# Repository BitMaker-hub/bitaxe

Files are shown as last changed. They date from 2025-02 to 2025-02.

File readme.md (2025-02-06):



# The Nerdaxe
NerdAxe is a fork from bitaxe with fullcolor display graphics. NerdAxe is indented to be an upgrade board for these who have a NerdMiner and would like to have more powerful mining features without losing the NerdMiner essence. That's why NerdAxe is currently controlled by the common board used on Nerdminer project called TTGO-TDisplayS3.

Currently exists two variants sepparated in two branches:
- **Nerdaxe Gamma**: 1,2Th with a single chip BM1370. [Nerdaxe Gamma](https://github.com/BitMaker-hub/NerdAxe/tree/gamma-1%2C2Ths)
- **Nerdaxe Ultra**: 0,5Th with a single chip BM1366. [Nerdaxe Ultra](https://github.com/BitMaker-hub/NerdAxe/tree/ultra-500Ghs)

The following fork could not be possible without the previous work of @skot, @ben & bitaxe devs. [Check bitaxe project](https://bitaxe.org)

Upgrade your NerdMiner experience throught this addon board and start playing with ASICs

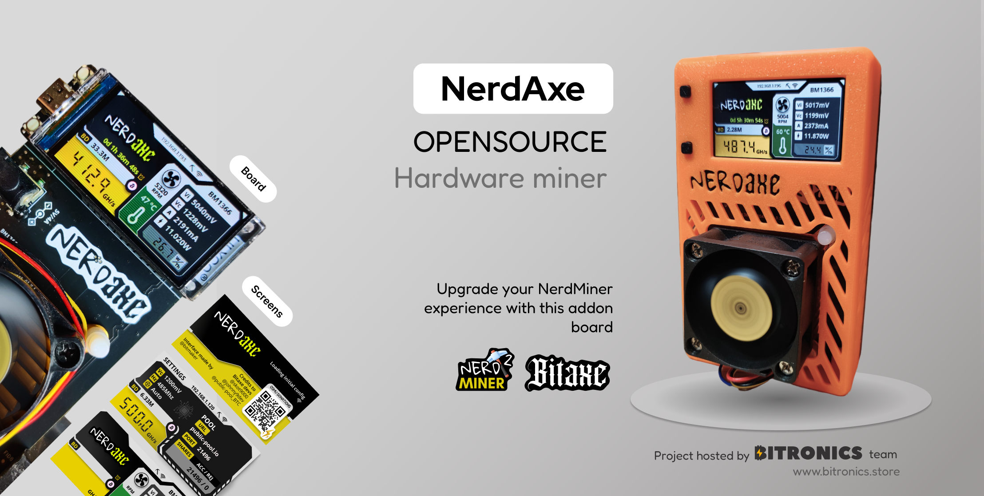
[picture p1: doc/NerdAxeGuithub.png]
NerdAxeUltra design


## Goals
- **Plug&Play**: your NerdMiner board and convert it into a NerdAxe.
- **Standalone**: can mine directly to your pool over WiFi. No External computer needed.
- **Embedded**: low cost, low maintenance, high availability, high reliability, low power.
- **ASIC**: working with most efficient ASIC chips from Bitmain - BM1370.
- **Versatile**: solo/pool mining, autotune power/heat/efficiency.
- **Open Source**: All design files are provided.

## Features
- **TTGO-TDisplay** ESP32s3 wifi microcontroller display board
- **Multiple Screens** to allow you see all the miner stats 
- **TI TPS546D** buck regulator steps down the 5V input to power the BM1370
- **Microchip EMC2101** PWM controls the fan and monitors tach output. Measuring internal die temp isn't working.

## Software & Firmware
Nerdaxe firmware was forked from original ESP-Miner version and adapted to use TTGO board and LVGL as graphic interface lib. 
Check it here -> [ESP-Miner Nerdaxe version](https://github.com/BitMaker-hub/ESP-Miner-NerdAxe)

**Today** Nerdaxe is using the latest evolution of this firmware modified by @pmaxuw (creator of the NerdQaxe) and used for other multiple boards
Current firmware -> [ESP-Miner Nerd\*axe version](https://github.com/shufps/ESP-Miner-NerdQAxePlus)

Flash the latest Nerdaxe firmware here: 
- Go to flasher online tool: https://flasher.bitronics.store/ (recommend via Google Chrome incognito mode)
- Nerd\*axe flasher online tool: https://shufps.github.io/nerdqaxe-web-flasher/  

## The DIY area

### Asic BM1370
- The BM1370 is a undocumented SHA256 mining ASIC from Bitmain. It's mostly used in the Antminer S21pro/S21+
- Bitmain claims the BM1370 has 0.021J/GH efficiency
- The BM1370 is available (new) for around $60 each in small quantities.
- The BM1370 has a different footprint and pinout from the MB1366, BM1368 in previous bitaxe.

### Other components & build troubleshooting
- BM1370 from NBTC on AliExpress
- [40x40mm heatsink and 5V fan](https://www.aliexpress.com/item/2251832861666365.html) from a random AliExpress seller. At least half of these arrived broken in some way. But they are cheap and the working ones do keep the BM1387's nice and cool when used with some thermal compound.
    - Swap this fan with the [Noctua NF-A4x10](https://noctua.at/en/products/fan/nf-a4x10-pwm) 5V 4-Pin fan for a much more pleasant experience.
- Board is designed with [KiCad 8](https://www.kicad.org) design files
- All of the parts on the board are listed in the KiCad BOM
- Check out [building.md](building.md) for PCB ordering tips
- Check out [assembly.md](assembly.md) for assembly tips

### Power Supply Requirements
- 5VDC Power supply 5A minimum. Should be capable of over 25W

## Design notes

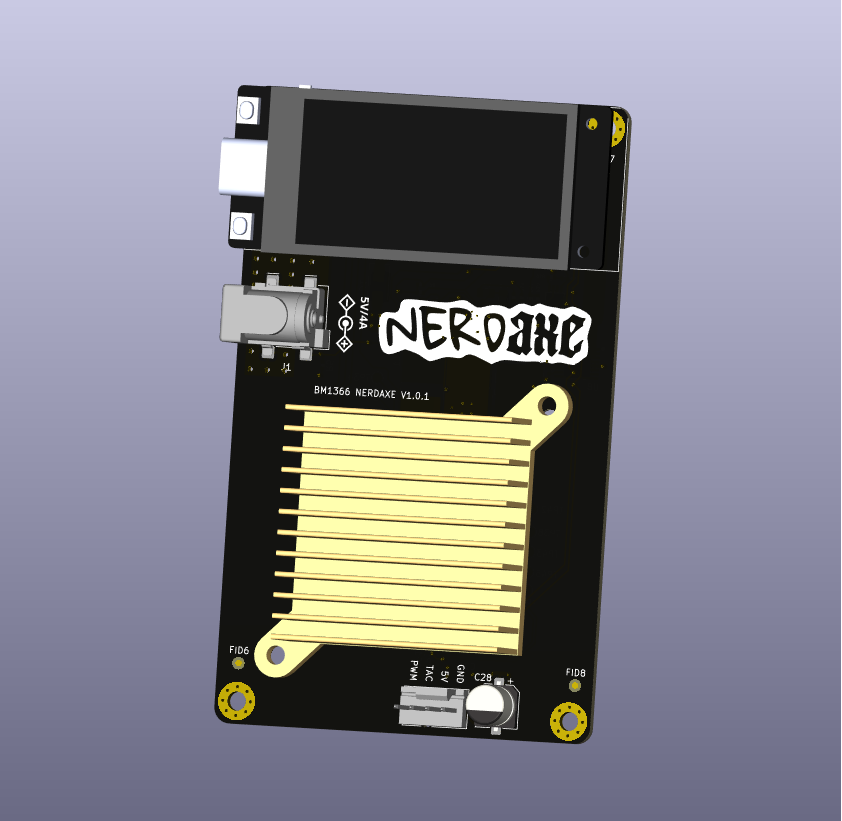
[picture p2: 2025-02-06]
doc/NerdAxe.png

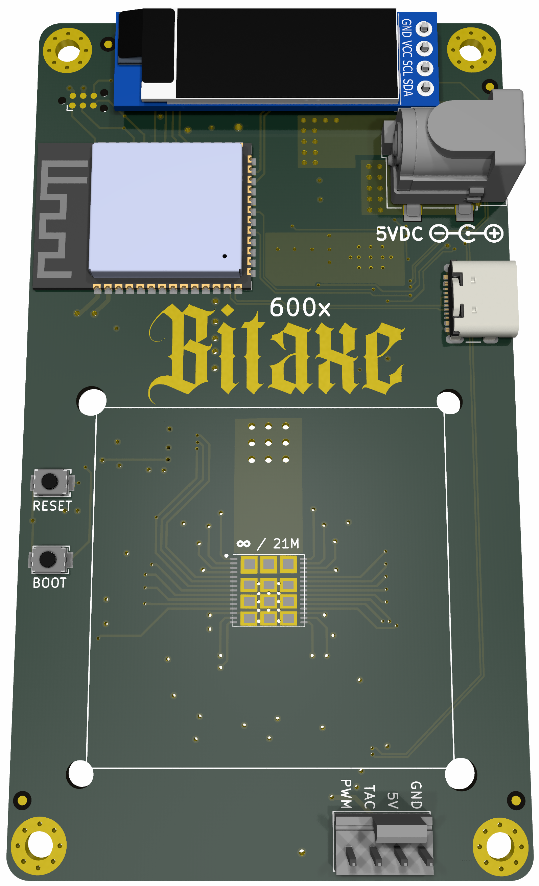
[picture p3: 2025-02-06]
doc/render.png

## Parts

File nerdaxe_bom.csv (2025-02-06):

Qty | Reference | Value | Footprint | DK | LCSC | Description
1 | C2 | 10uF | Capacitor_SMD:C_0805_2012Metric | 1276-1096-1-ND
1 | C6 | 4700pF | Capacitor_SMD:C_0402_1005Metric | 490-1309-1-ND
1 | C9 | 2200pF | Capacitor_SMD:C_0402_1005Metric | 490-8257-1-ND
1 | C10 | 4.7uF | Capacitor_SMD:C_0402_1005Metric | 490-14306-1-ND
1 | C11 | 1000pF | Capacitor_SMD:C_0805_2012Metric | 311-1127-1-ND
1 | C13 | 100pF | Capacitor_SMD:C_0402_1005Metric | 732-7431-1-ND
1 | C50 | 470pF | Capacitor_SMD:C_0402_1005Metric | 1276-1566-1-ND
21 | C1 C5 C7 C26 C27 C28 C30 C31 C32 C33 C34 C35 C36 C39 C40 C41 C42 C44 C45 C46 C48 | 1uF | Capacitor_SMD:C_0402_1005Metric | 587-5514-1-ND
3 | C14 C15 C16 | 22uF | Capacitor_SMD:C_0805_2012Metric | 490-10746-1-ND
5 | C17 C18 C19 C20 C43 | 100uF | Capacitor_SMD:C_1206_3216Metric | 1276-1782-1-ND |  | -- valores mixtos --
3 | C3 C4 C51 | 47uF | Capacitor_SMD:C_1210_3225Metric | 1276-3376-1-ND
9 | C8 C12 C29 C37 C38 C47 C49 C52 C53 | 0.1uF | Capacitor_SMD:C_0402_1005Metric | 1276-1234-1-ND
1 | D1 | SMAJ5.0A | Diode_SMD:D_SMA |  |  | 400W unidirectional Transient Voltage Suppressor | 5.0Vr | SMA(DO-214AC)
1 | J1 | 54-00164 | bitaxe:TENSILITY_54-00164 | 839-54-00164CT-ND | C431534 | DC Barrel Jack with an internal switch
1 | J6 | Conn_01x04 | bitaxe:470531000 | WM4330-ND
1 | L1 | 300nH | bitaxe:SLC1175-271MEC_COC
1 | R1 | 8.25k | Resistor_SMD:R_0402_1005Metric | 311-8.25KLRCT-ND
1 | R5 | 14.7k | Resistor_SMD:R_0402_1005Metric | YAG2984CT-ND
1 | R8 | 3.74k | Resistor_SMD:R_0402_1005Metric | 311-3.74KLRCT-ND
1 | R9 | 11.8k | Resistor_SMD:R_0402_1005Metric | YAG2958CT-ND
1 | R10 | 68.1k | Resistor_SMD:R_0402_1005Metric | YAG3213CT-ND
1 | R11 | 10 | Resistor_SMD:R_0402_1005Metric | 311-10.0LRCT-ND
1 | R12 | 1 | Resistor_SMD:R_1206_3216Metric | CSR1206FT1R00CT-ND
1 | R24 | 5.6k | Resistor_SMD:R_0402_1005Metric | 13-RC0402FR-135K6LCT-ND
2 | R13 R14 | 49.9 | Resistor_SMD:R_0402_1005Metric | 311-49.9LRCT-ND
3 | R15 R17 R25 | 10k | Resistor_SMD:R_0402_1005Metric | 311-10KJRCT-ND
2 | R18 R19 | 1k | Resistor_SMD:R_0402_1005Metric | 311-1.00KLRCT-ND
2 | R22 R23 | 100 | Resistor_SMD:R_0402_1005Metric | 311-100LRCT-ND
2 | R6 R21 | 0 | Resistor_SMD:R_0402_1005Metric | -- valores mixtos --
1 | U2 | TPS546D24ARVFR | bitaxe:LQFN40-CLIP | 296-TPS546D24ARVFRCT-ND
1 | U5 | MCP1824T-1202E/OT | Package_TO_SOT_SMD:SOT-23-5 | MCP1824T-1202E/OTCT-ND
1 | U6 | MCP1824T-0802E | Package_TO_SOT_SMD:SOT-23-5 | MCP1824T-0802E/OTCT-ND
1 | U7 | 25MHz | bitaxe:SMD3225-4P |  | C5137262
1 | U8 | BM1370_mode1 | bitaxe:BM1370
1 | U9 | SN74AVC4T774 | Package_SO:TSSOP-16_4.4x5mm_P0.65mm | 296-24739-1-ND
1 | U10 | EMC2101 | Package_SO:TSSOP-8_3x3mm_P0.65mm | EMC2101-R-ACZL-CT-ND
1 | U11 | T-Display-S3 | bitaxe:T-Display-S3

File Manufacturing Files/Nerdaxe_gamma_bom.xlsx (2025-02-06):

Comment | Designator | Footprint | JLCPCB part
4700pF (GRM155R71E472KA01D) | C6 | Condensador 0402 4700PF 25V X7R estándar | C1538
2200pF (GRM155R61H222KA01D) | C9 | Condensador 0402 2200PF 50V X5R | C1531
4.7uF | C10 | Condensador 0402 4.7UF 10V X5R estándar | C191541
1000pF | C11 | Condensador 0805 1000pF 50V estándar | C94121
100pF | C13 | Condensador 0402 100pF/50V XR7 estándar | C281750
470pF | C50 | Condensador 0402 470pF/50V XR7 estándar | C272887
1uF | C1, C5, C7, C26, C27, C28, C30, C31, C32, C33, C34, C35, C36, C39, C40, C41, C42, C44, C45, C46, C48 | Condensador 0402 1uF 16V XR5 estándar | C113791
22uF (GRM21BR61A226ME44L) | C14, C15, C16 | Condensador 0805 22uF 10V estándar | C29277
100uF (CL31A107MQHNNNE) | C17, C18, C19, C20, C43 | Condensador 1206 100uF 6.3V XR5 estándar | C87164
10uF | C2 | Condensador 0805 10uF 16V XR5 estándar | C89827
47uF (CL32A476KOJNNNE) | C3, C4, C51 | Condensador 1210 47uF 16V XR5 estándar | C412625
0.1uF | C8, C12, C29, C37, C38, C47, C49, C52, C53 | Condensador 0402 100nF 16V estándar | C1525
SMAJ5.0A | D1 | SMAJ5.0A | C113952
US1D | D2 | Diode_SMD:D_SMA | C5140042
Conn_01x04 | J6 | 470531000 | C240840
8.25k | R1 | Resistencia 0402 8.25k estandar | C95598
14.7k | R5 | Resistencia 0402 14k7 1% estandar | C881164
0 | R6, R21 | Resistencia 0402 0ohm estandar | C106231
3.74k | R8 | Resistencia 0402 3.74k 1% estandar | C15172
11.8k | R9 | Resistencia 0402 11.8k 1% estandar | C93752
68.1k | R10 | Resistencia 0402 68.1k 1% estandar | C11537
10 | R11 | Resistencia 0402 10ohm 1% estandar | C25139
1 | R12 | Resistencia 1206 1ohm 1% estandar | C17928
5.6k | R24 | Resistencia 0402 5k6 1% estandar | C365033
49.9 | R13, R14 | Resistencia 0402 49.9 1% estandar | C477760
10k | R15, R17, R25 | Resistencia 0402 10k 1% estandar | C269674
1k | R19 | Resistencia 0402 1k 1% estandar | C11702
100 | R22, R23 | Resistencia 0402 100 1% estandar | C25076
TPS546D24ARVFR | U2 | TPS546D24ARVFR | C507280
MCP1824T-1202E/OT | U5 | MCP1824T-1202E/OT | C58464
MCP1824T-0802E | U6 | MCP1824T-0802E/OT | C625460
SX3M25.000E20F30THN | U7 | 25MHz - SX3M25.000E20F30THN | C5137262
SN74AVC4T774PWR | U9 | SN74AVC4T774PWR - TSSOP-16 | C129363
EMC2101-R-ACZL-TR | U10 | EMC2101 - TSSOP-8 | C626968
 | Observaciones
 | Muy atentamente,

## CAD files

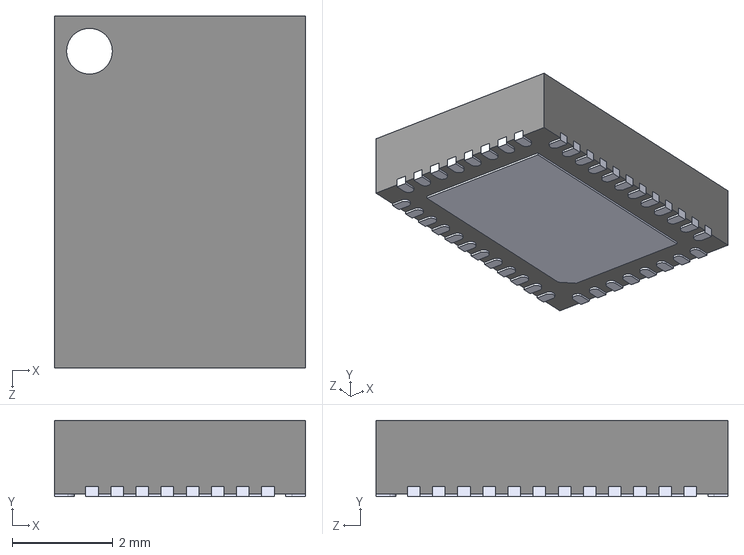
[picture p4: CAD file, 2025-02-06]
3d/TPS546D24ARVFR.step
5.00 x 1.52 x 7.00 mm

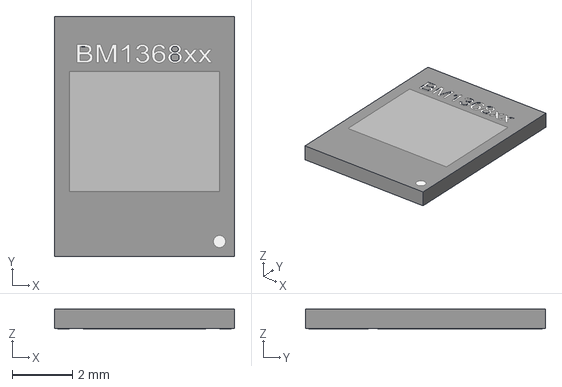
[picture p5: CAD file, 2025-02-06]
3d/BM1368xx.stp
6.00 x 8.00 x 0.65 mm

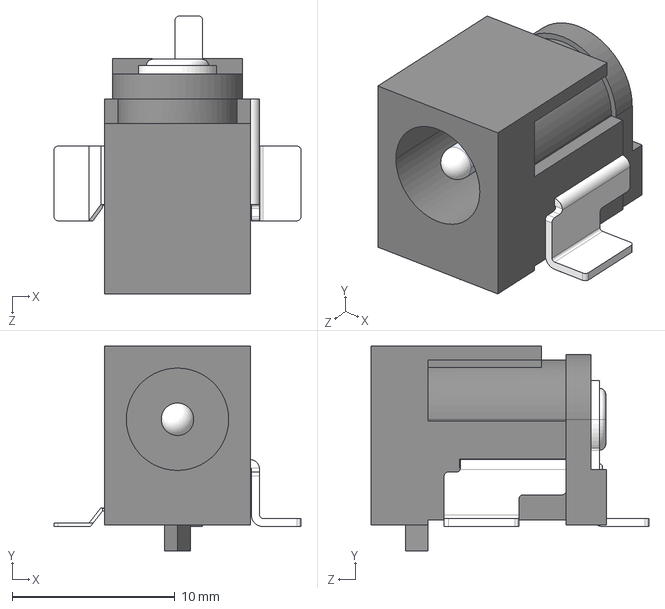
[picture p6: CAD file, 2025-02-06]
3d/CUI_DEVICES_PJ-036AH-SMT-TR.step
15.2 x 12.6 x 17.1 mm

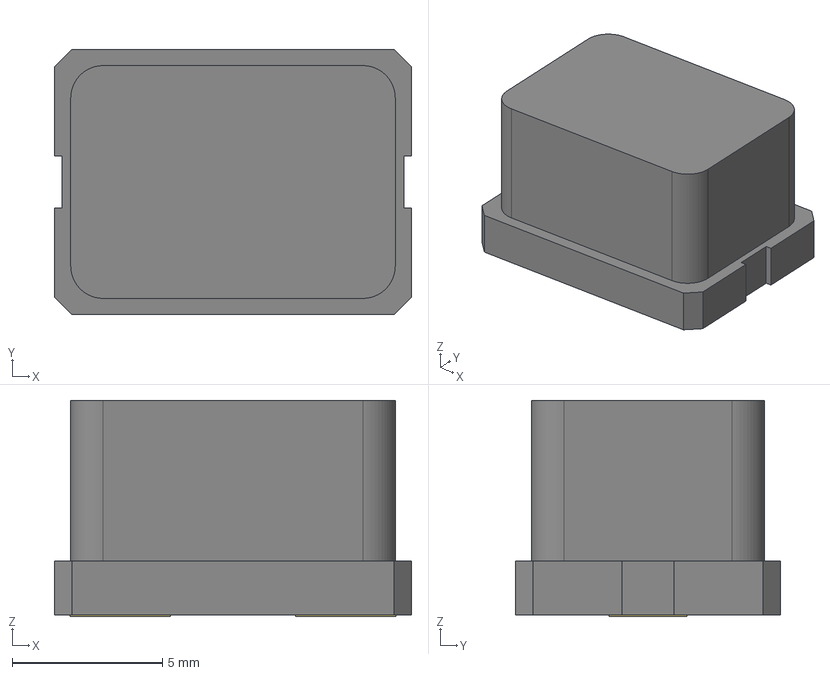
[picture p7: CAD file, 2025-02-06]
3d/SLC1175-271MEC_COC.step
11.9 x 8.83 x 7.19 mm

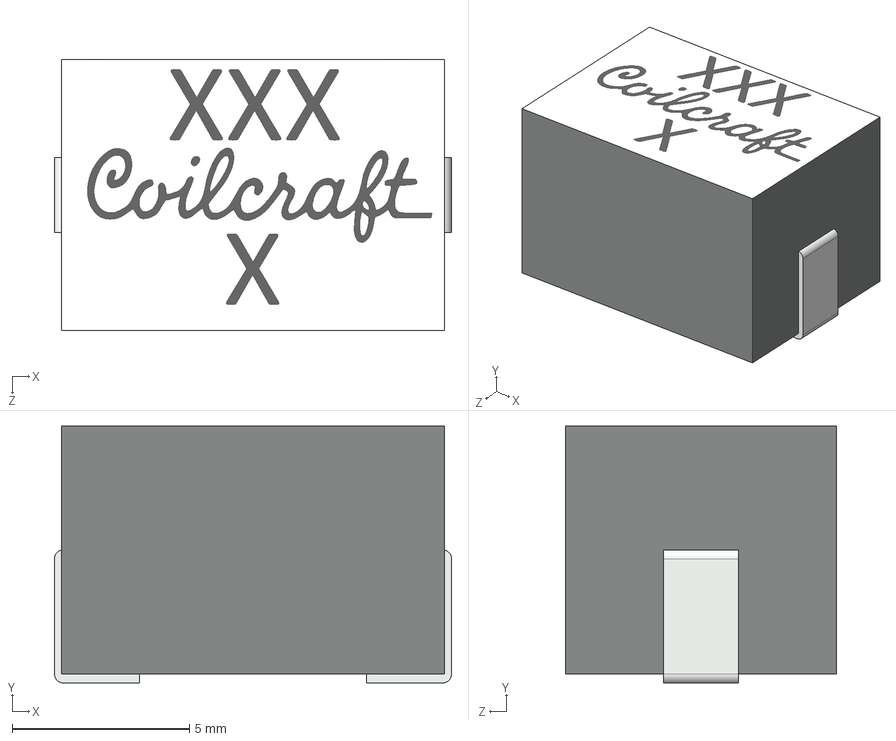
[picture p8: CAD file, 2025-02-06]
3d/Coilcraft-SLC1175.STEP
11.2 x 7.25 x 7.65 mm

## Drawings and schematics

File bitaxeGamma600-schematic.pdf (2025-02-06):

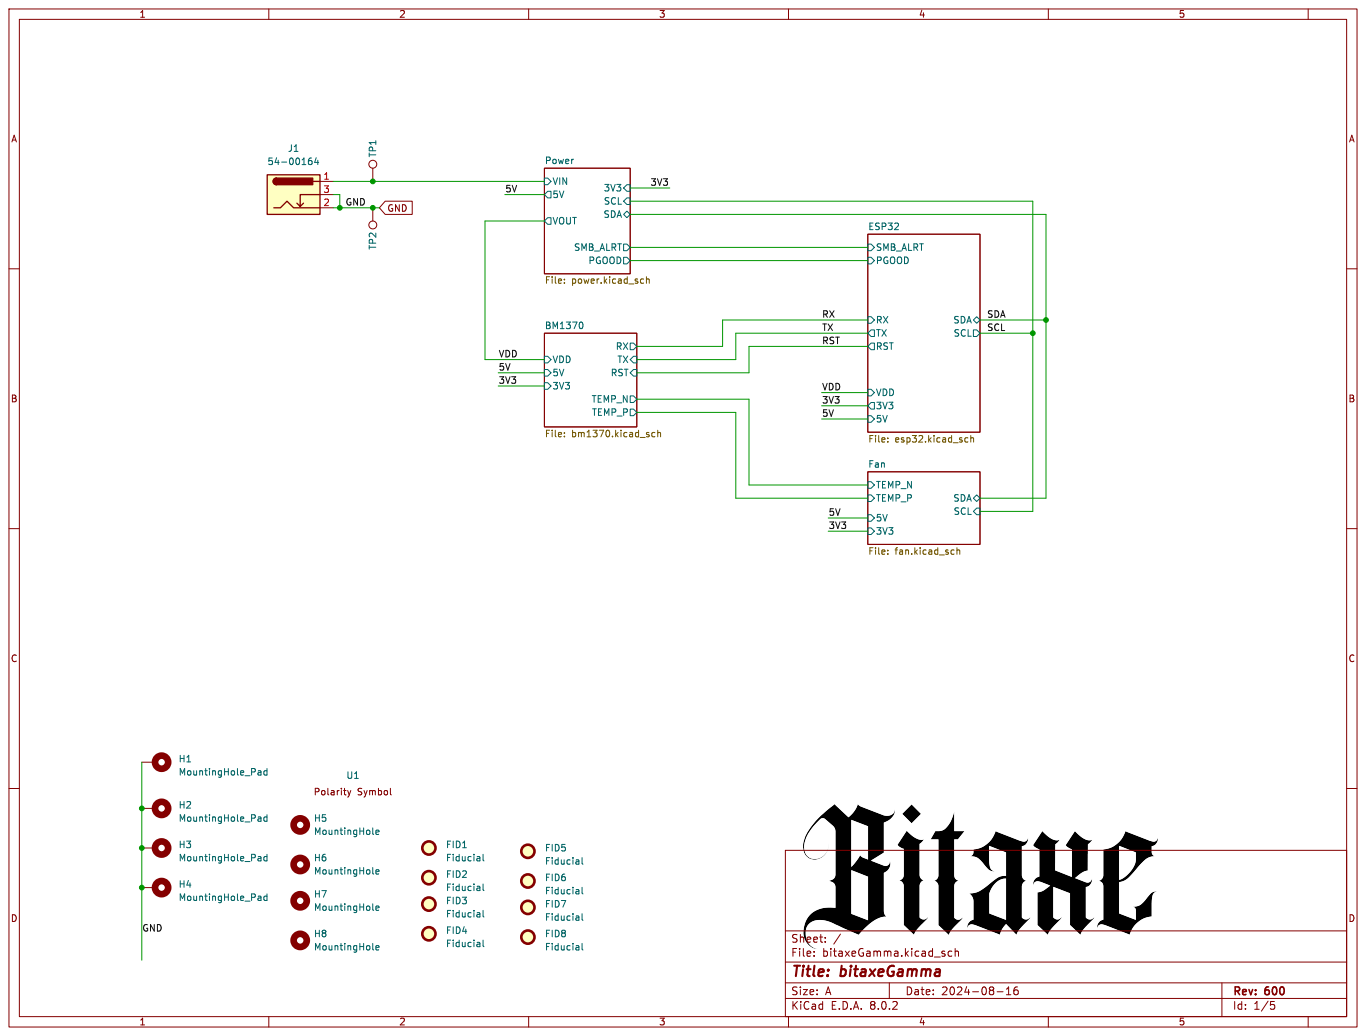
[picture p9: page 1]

Fan File: fan.kicad_sch TXRX RST

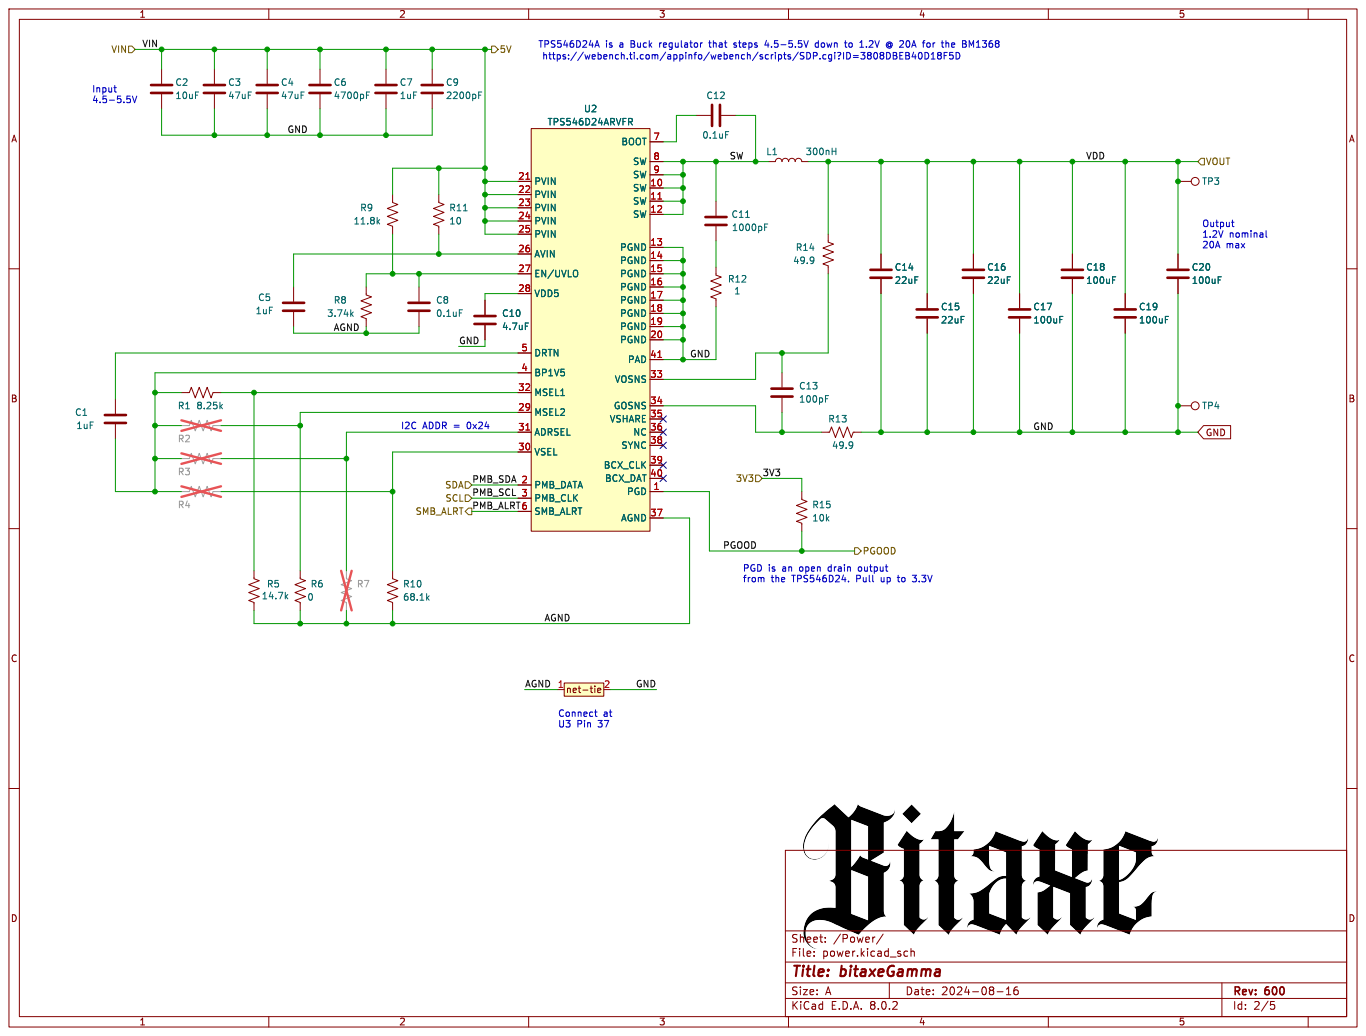
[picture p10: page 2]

https://webench.ti.com/appinfo/webench/scripts/SDP.cgi?ID=3808DBEB40D18F5D

File: power.kicad_sch Sheet: /Power/
Id: 2/5 Title: bitaxeGamma

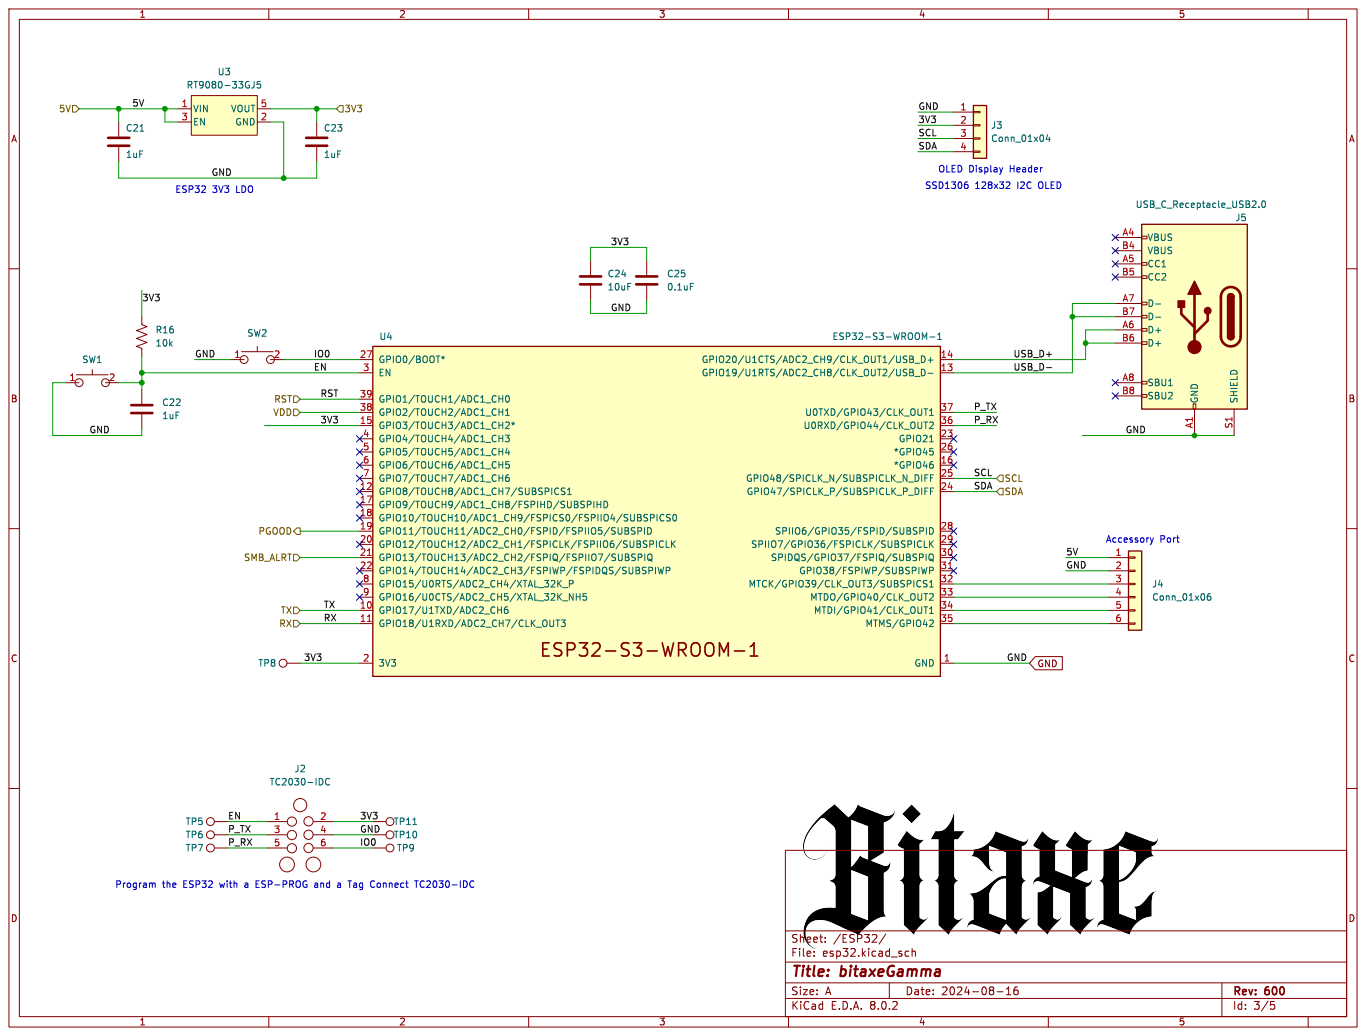
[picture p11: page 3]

Program the ESP32 with a ESP-PROG and a Tag Connect TC2030-IDC

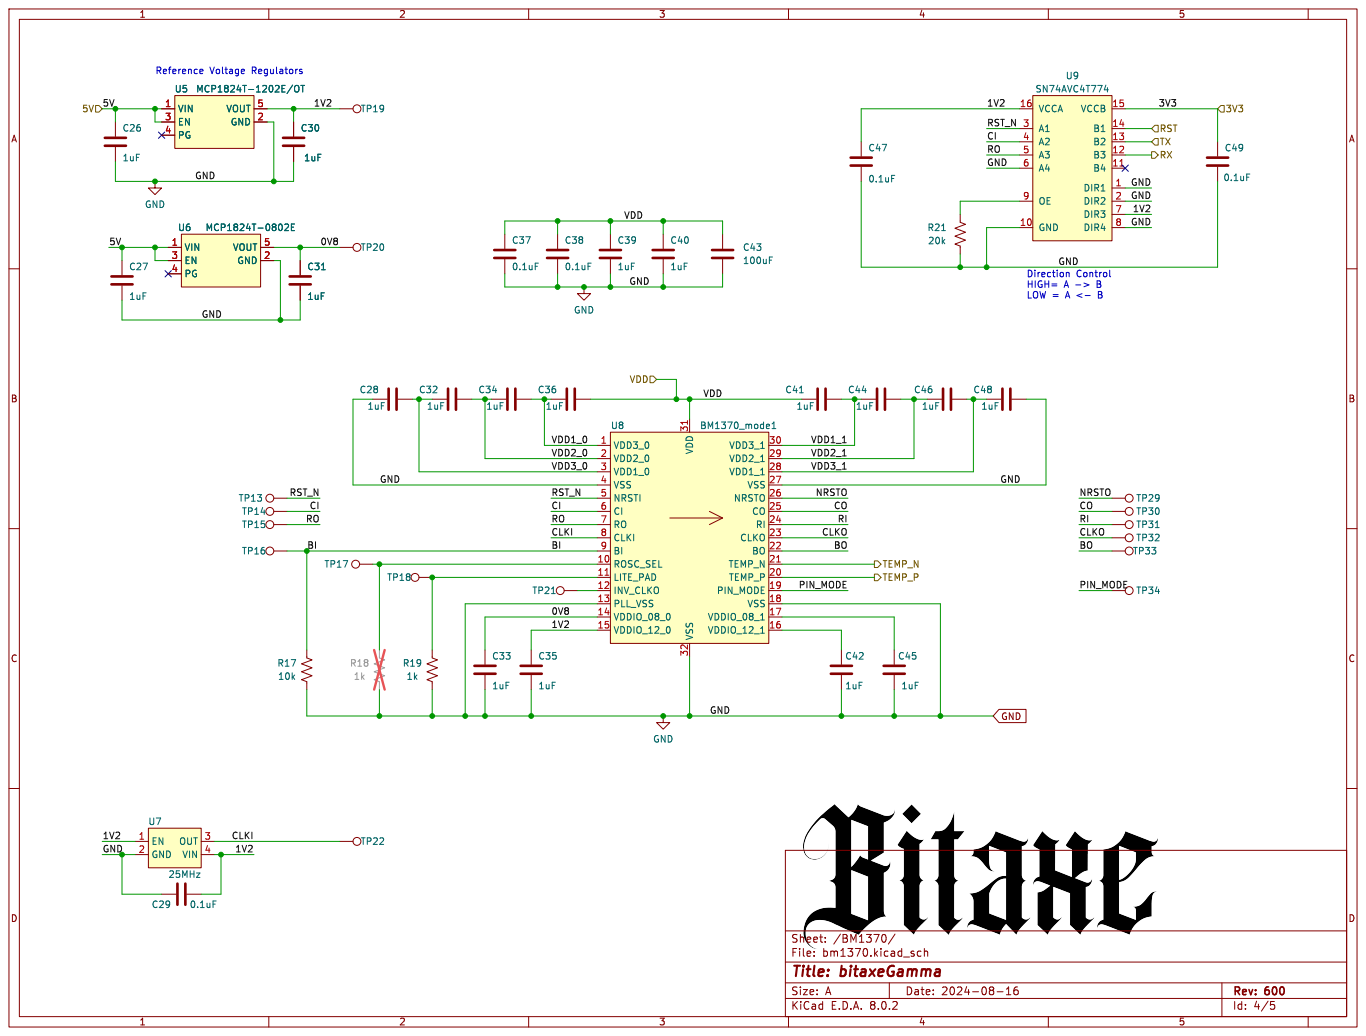
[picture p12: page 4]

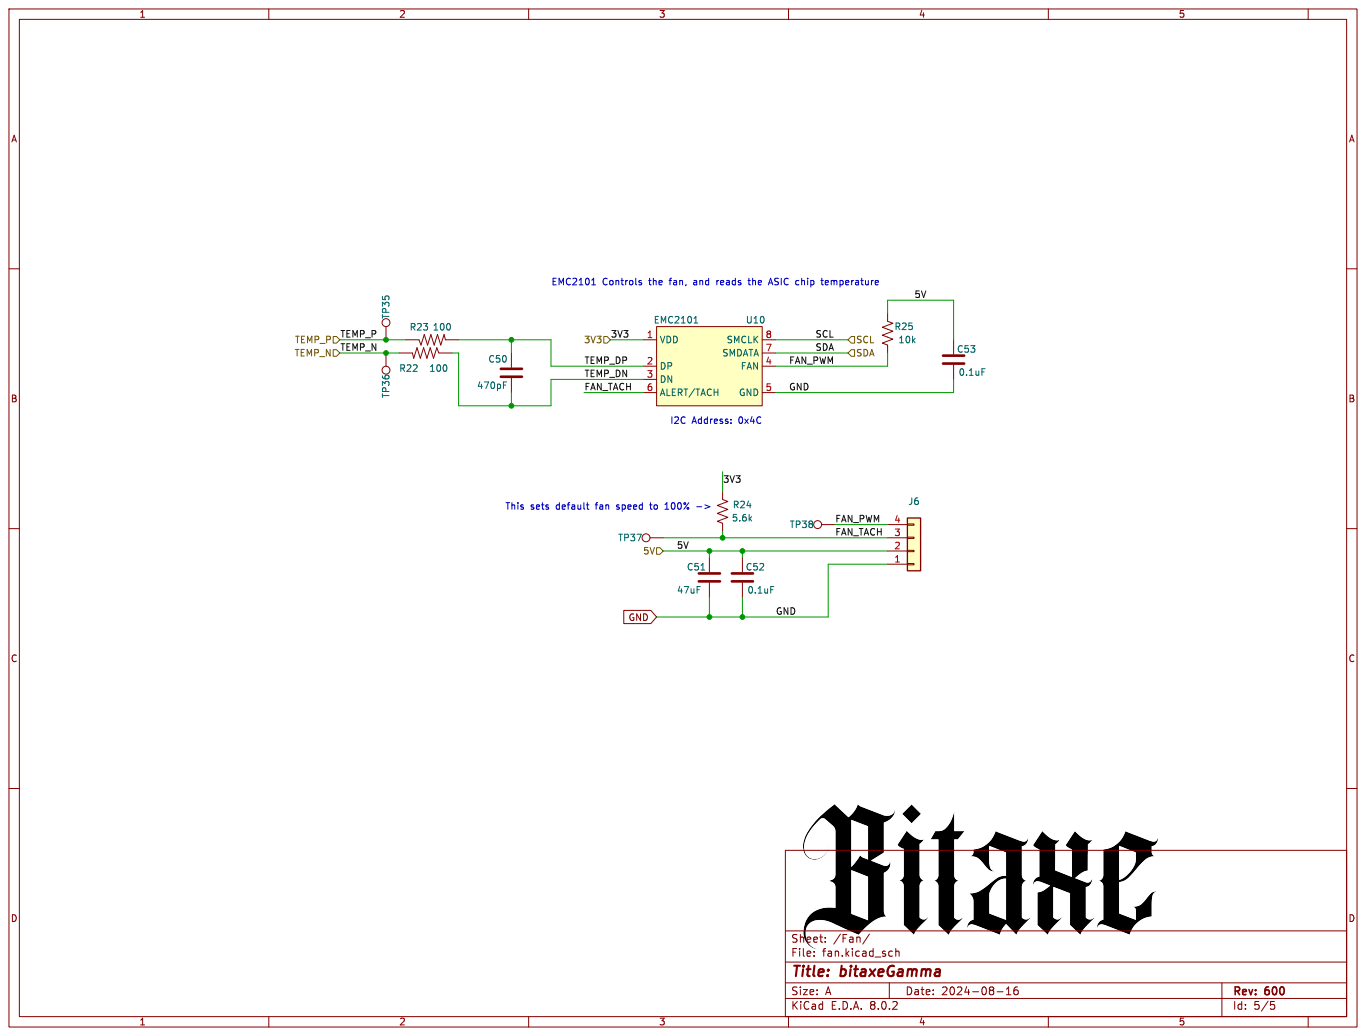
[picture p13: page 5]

File: fan.kicad_sch Sheet: /Fan/ R24

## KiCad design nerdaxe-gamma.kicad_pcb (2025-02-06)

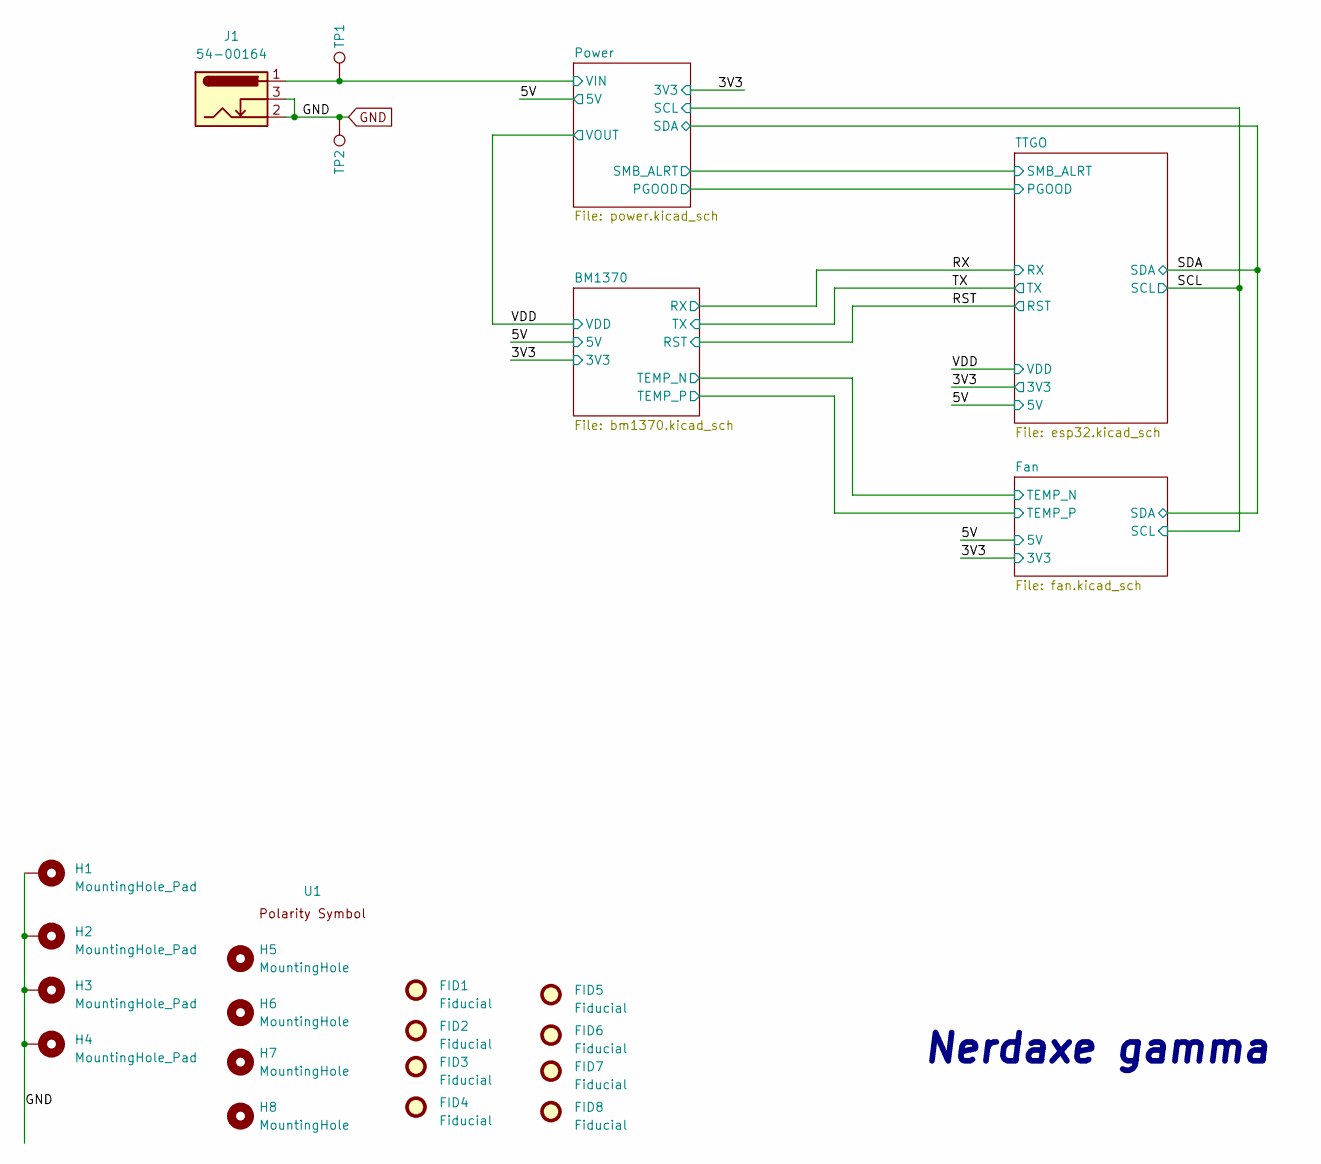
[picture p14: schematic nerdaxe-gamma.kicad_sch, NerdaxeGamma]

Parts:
FID1, FID2, FID3, FID4, FID5, FID6, FID7, FID8: Fiducial; Fiducial_1mm_Mask2mm
H1, H2, H3, H4: MountingHole_Pad; MountingHole_3mm_Pad_Via
H5, H6, H7, H8: MountingHole; MountingHole_3.5mm
J1: 54-00164; TENSILITY_54-00164; PARTNO 54-00164; LCSC C431534
TP1, TP2: TestPoint; TestPoint_Pad_D1.5mm
U1: polarity

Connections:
/5V: J1.1, TP1.1; also elsewhere on the board

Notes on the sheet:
Nerdaxe gamma

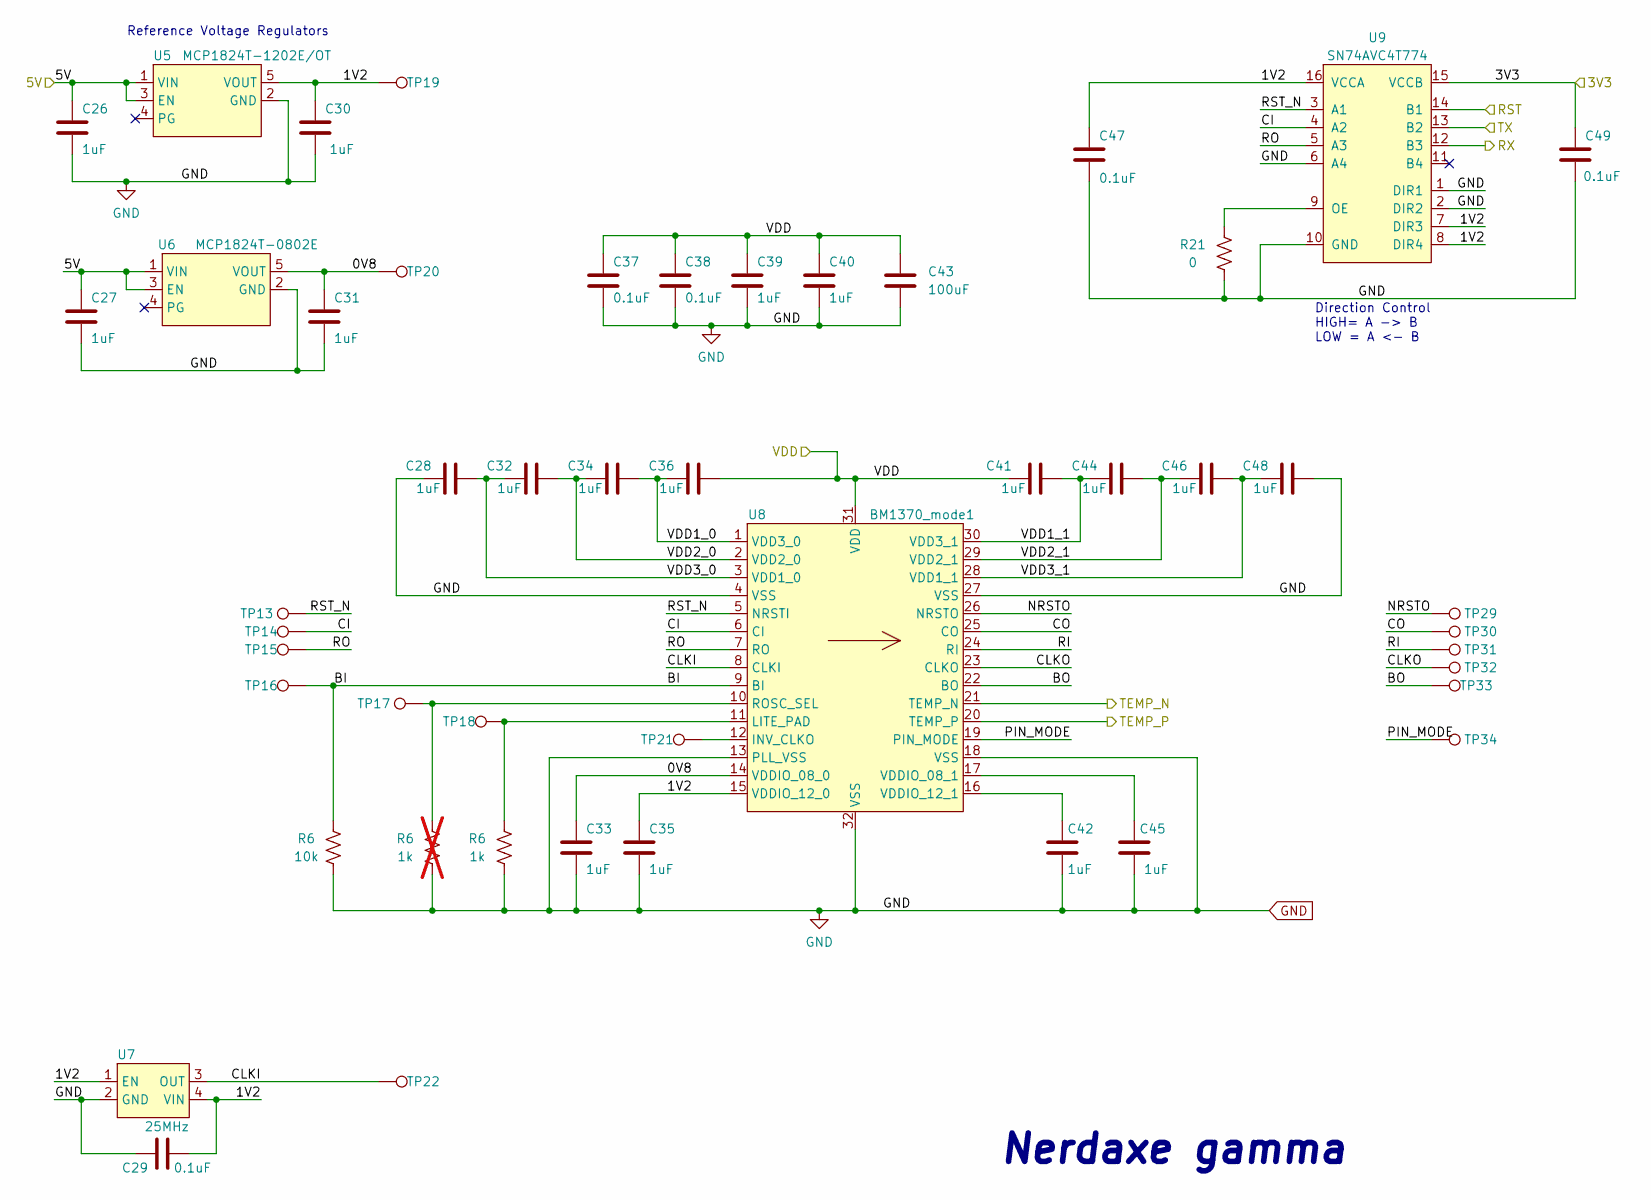
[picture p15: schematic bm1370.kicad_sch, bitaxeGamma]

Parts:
C26, C27, C28, C30, C31, C32, C33, C34, C35, C36, C39, C40, C41, C42, C44, C45, C46, C48: 1uF; C_0402_1005Metric; PARTNO EMK105BJ105MV-F
C29, C37, C38, C47, C49: 0.1uF; C_0402_1005Metric; PARTNO CL05A104KO5NNNC
C43: 100uF; C_1206_3216Metric; PARTNO CL31A107MQHNNNE
R6: 1k; R_0402_1005Metric; PARTNO RC0402FR-071KL; not fitted
R21: 0; R_0402_1005Metric; PARTNO RC0402FR-0720KL
TP13, TP14, TP15, TP16, TP17, TP18, TP19, TP20, TP21, TP22, TP29, TP30, TP31, TP32, TP33, TP34: TestPoint; TestPoint_Pad_D1.5mm
U5: MCP1824T-1202E/OT; SOT-23-5; PARTNO MCP1824T-1202E/OT
U6: MCP1824T-0802E; SOT-23-5; PARTNO MCP1824T-0802E/OT
U7: 25MHz; SMD3225-4P; PARTNO SX3M25.000E20F30THN; LCSC C5137262
U8: BM1370_mode1; BM1370
U9: SN74AVC4T774; TSSOP-16_4.4x5mm_P0.65mm; PARTNO SN74AVC4T774PWR

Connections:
/3V3: C49.1, U9.15 (VCCB); also elsewhere on the board
/5V: C26.1, C27.1, U5.1 (VIN), U5.3 (EN), U6.1 (VIN), U6.3 (EN); also elsewhere on the board
/BM1370/0V8: C31.1, C33.1, TP20.1, U6.5 (VOUT), U8.14 (VDDIO_08_0)
/BM1370/1V2: C29.2, C30.1, C35.1, C47.1, TP19.1, U5.5 (VOUT), U7.1 (EN), U7.4 (VIN), U8.15 (VDDIO_12_0), U9.7 (DIR3), U9.8 (DIR4), U9.16 (VCCA)
/BM1370/BO: TP33.1, U8.22 (BO)
/BM1370/CI: TP14.1, U8.6 (CI), U9.4 (A2)
/BM1370/CLKI: TP22.1, U7.3 (OUT), U8.8 (CLKI)
/BM1370/CLKO: TP32.1, U8.23 (CLKO)
/BM1370/CO: TP30.1, U8.25 (CO)
/BM1370/NRSTO: TP29.1, U8.26 (NRSTO)
/BM1370/PIN_MODE: TP34.1, U8.19 (PIN_MODE)
/BM1370/RI: TP31.1, U8.24 (RI)
/BM1370/RO: TP15.1, U8.7 (RO), U9.5 (A3)
/BM1370/RST_N: TP13.1, U8.5 (NRSTI), U9.3 (A1)
/BM1370/VDD1_0: C34.2, C36.1, U8.1 (VDD3_0)
/BM1370/VDD1_1: C41.2, C44.1, U8.30 (VDD3_1)
/BM1370/VDD2_0: C32.2, C34.1, U8.2 (VDD2_0)
/BM1370/VDD2_1: C44.2, C46.1, U8.29 (VDD2_1)
/BM1370/VDD3_0: C28.2, C32.1, U8.3 (VDD1_0)
/BM1370/VDD3_1: C46.2, C48.1, U8.28 (VDD1_1)
/Fan/TEMP_N: U8.21 (TEMP_N); also elsewhere on the board
/Fan/TEMP_P: U8.20 (TEMP_P); also elsewhere on the board
/RST: U9.14 (B1); also elsewhere on the board
/RX: U9.12 (B3); also elsewhere on the board
/TX: U9.13 (B2); also elsewhere on the board
/VDD: C36.2, C37.1, C38.1, C39.1, C40.1, C41.1, C43.1, U8.31 (VDD); also elsewhere on the board
unnamed: TP21.1, U8.12 (INV_CLKO)
unnamed: C45.1, U8.17 (VDDIO_08_1)
unnamed: C42.1, U8.16 (VDDIO_12_1)
unnamed: R21.2, U9.9 (OE)

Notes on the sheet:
Reference Voltage Regulators
Direction Control HIGH= A -> B LOW = A <- B
Nerdaxe gamma

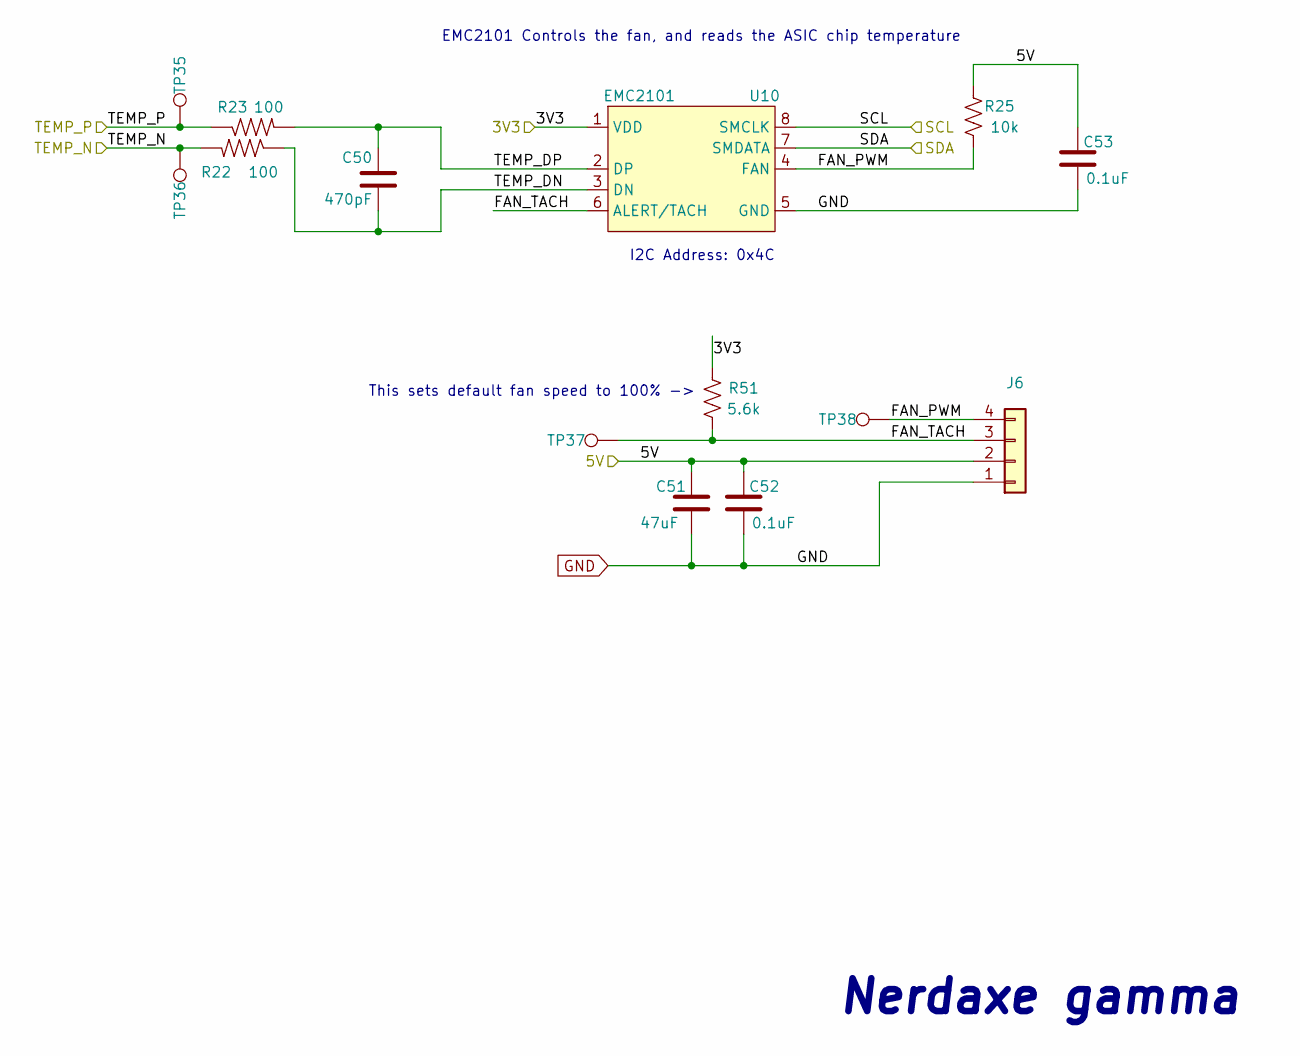
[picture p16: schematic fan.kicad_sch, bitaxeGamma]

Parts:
C50: 470pF; C_0402_1005Metric; PARTNO CL05B471KB5NNNC
C51: 47uF; C_1210_3225Metric; PARTNO CL32A476KOJNNNE
C52, C53: 0.1uF; C_0402_1005Metric; PARTNO CL05A104KO5NNNC
J6: Conn_01x04; 470531000; PARTNO 0470531000
R22, R23: 100; R_0402_1005Metric; PARTNO RC0402FR-07100RL
R25: 10k; R_0402_1005Metric; PARTNO RC0402JR-0710KL
R51: 5.6k; R_0402_1005Metric; PARTNO RC0402FR-135K6L
TP35, TP36, TP37, TP38: TestPoint; TestPoint_Pad_D1.5mm
U10: EMC2101; TSSOP-8_3x3mm_P0.65mm; PARTNO EMC2101-R-ACZL-TR

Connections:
/3V3: U10.1 (VDD); also elsewhere on the board
/5V: C51.1, C52.1, C53.1, J6.2, R25.2; also elsewhere on the board
/Fan/FAN_PWM: J6.4, R25.1, TP38.1, U10.4 (FAN)
/Fan/FAN_TACH: J6.3, TP37.1, U10.6 (ALERT/TACH); also elsewhere on the board
/Fan/TEMP_DN: C50.2, R22.1, U10.3 (DN)
/Fan/TEMP_DP: C50.1, R23.2, U10.2 (DP)
/Fan/TEMP_N: R22.2, TP36.1; also elsewhere on the board
/Fan/TEMP_P: R23.1, TP35.1; also elsewhere on the board
/SCL: U10.8 (SMCLK); also elsewhere on the board
/SDA: U10.7 (SMDATA); also elsewhere on the board

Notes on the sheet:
Nerdaxe gamma
EMC2101 Controls the fan, and reads the ASIC chip temperature
This sets default fan speed to 100% ->
I2C Address: 0x4C

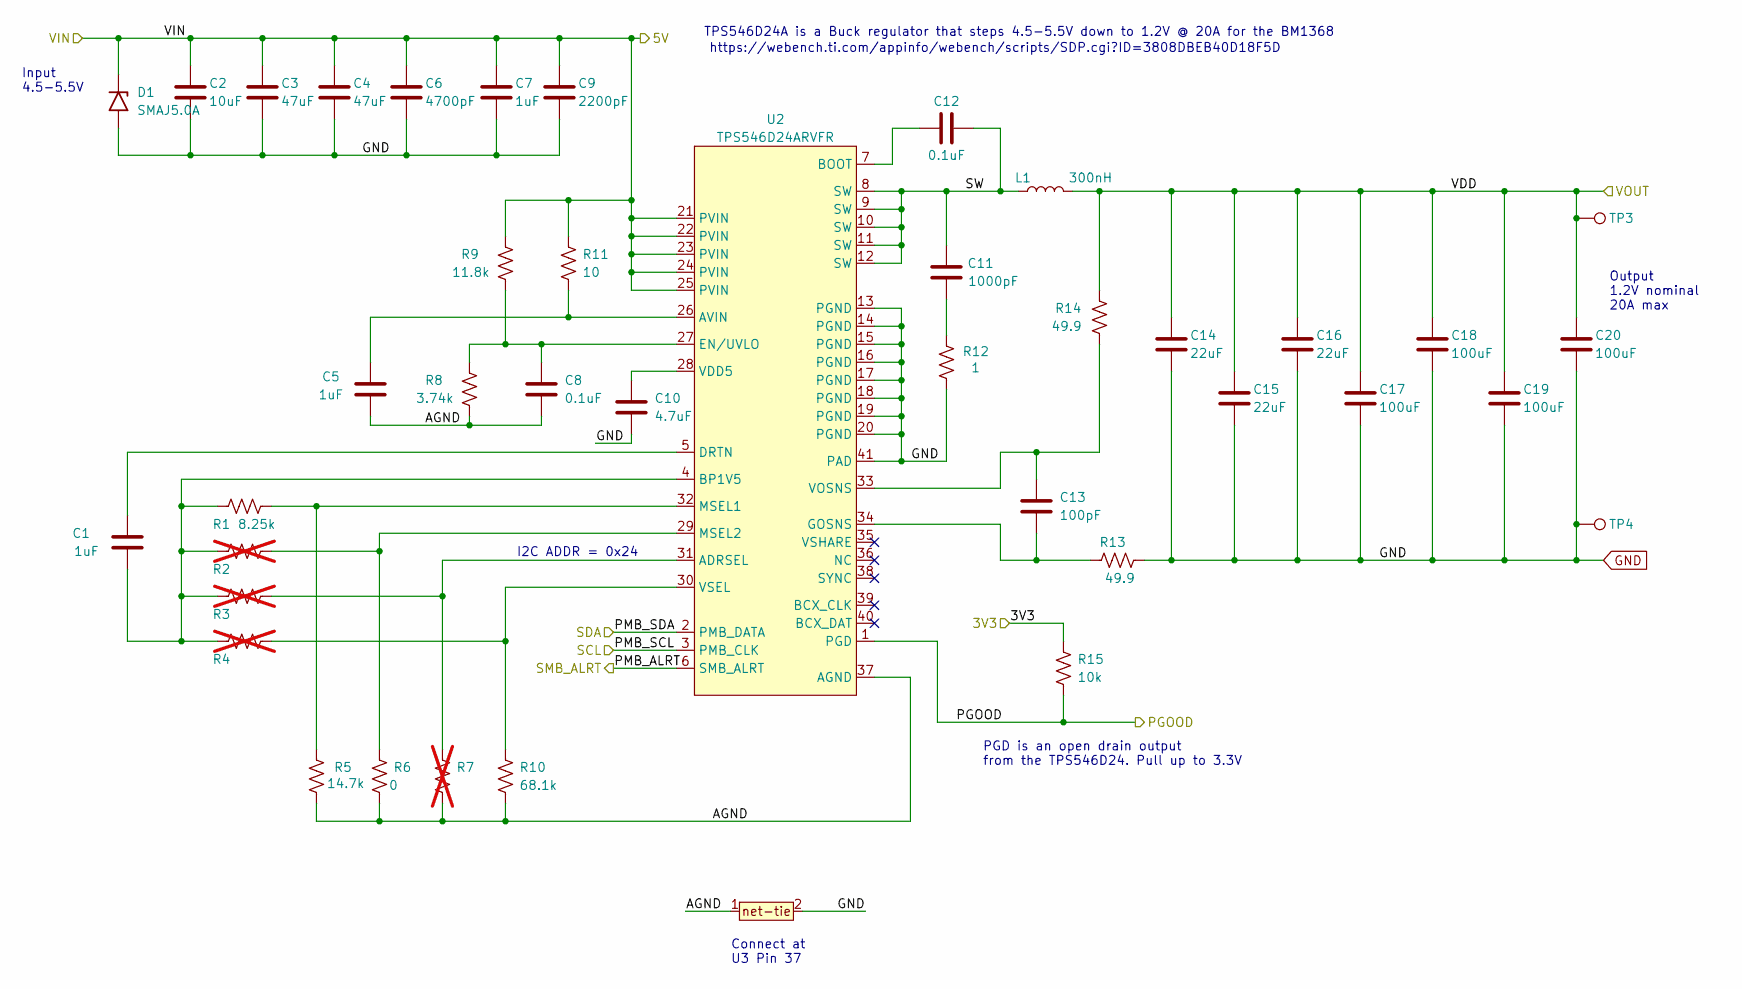
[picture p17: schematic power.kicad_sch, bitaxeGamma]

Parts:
C1, C5, C7: 1uF; C_0402_1005Metric; PARTNO EMK105BJ105MV-F
C2: 10uF; C_0805_2012Metric; PARTNO CL21A106KOQNNNE
C3, C4: 47uF; C_1210_3225Metric; PARTNO CL32A476KOJNNNE
C6: 4700pF; C_0402_1005Metric; PARTNO GRM155R71E472KA01D
C8, C12: 0.1uF; C_0402_1005Metric; PARTNO CL05A104KO5NNNC
C9: 2200pF; C_0402_1005Metric; PARTNO GRM155R61H222KA01D
C10: 4.7uF; C_0402_1005Metric; PARTNO GRM155R61A475MEAAD
C11: 1000pF; C_0805_2012Metric; PARTNO CC0805KRX7R9BB102
C13: 100pF; C_0402_1005Metric; PARTNO 885012005013
C14, C15, C16: 22uF; C_0805_2012Metric; PARTNO GRM21BR61A226ME44L
C17, C18, C19, C20: 100uF; C_1206_3216Metric; PARTNO CL31A107MQHNNNE
D1: SMAJ5.0A; D_SMA
L1: 300nH; SLC1175-271MEC_COC; PARTNO SLC1175-301MEC; Mouser 994-SLC1175-271MEC
R1: 8.25k; R_0402_1005Metric; PARTNO RC0402FR-078K25L
R2, R3, R4, R7: R_0402_1005Metric; not fitted
R5: 14.7k; R_0402_1005Metric; PARTNO RC0402FR-0714K7L
R6: 0; R_0402_1005Metric; PARTNO RC0402JR-070RL
R8: 3.74k; R_0402_1005Metric; PARTNO RC0402FR-073K74L
R9: 11.8k; R_0402_1005Metric; PARTNO RC0402FR-0711K8L
R10: 68.1k; R_0402_1005Metric; PARTNO RC0402FR-0768K1L
R11: 10; R_0402_1005Metric; PARTNO RC0402FR-0710RL
R12: 1; R_1206_3216Metric; PARTNO CSR1206FT1R00
R13, R14: 49.9; R_0402_1005Metric; PARTNO RC0402FR-0749R9L
R15: 10k; R_0402_1005Metric; PARTNO RC0402JR-0710KL
T1: net-tie; NetTie-0.25mm
TP3, TP4: TestPoint; TestPoint_Pad_D1.5mm
U2: TPS546D24ARVFR; LQFN40-CLIP; PARTNO TPS546D24ARVFR

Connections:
/3V3: R15.2; also elsewhere on the board
/5V: C2.1, C3.1, C4.1, C6.1, C7.1, C9.1, D1.1 (A1), R9.1, R11.1, U2.21 (PVIN), U2.22 (PVIN), U2.23 (PVIN), U2.24 (PVIN), U2.25 (PVIN); also elsewhere on the board
/Power/PGOOD: R15.1, U2.1 (PGD); also elsewhere on the board
/Power/PMB_ALRT: U2.6 (SMB_ALRT); also elsewhere on the board
/Power/SW: C11.2, C12.2, L1.1, U2.8 (SW), U2.9 (SW), U2.10 (SW), U2.11 (SW), U2.12 (SW)
/SCL: U2.3 (PMB_CLK); also elsewhere on the board
/SDA: U2.2 (PMB_DATA); also elsewhere on the board
/VDD: C14.1, C15.1, C16.1, C17.1, C18.1, C19.1, C20.1, L1.2, R14.1, TP3.1; also elsewhere on the board
unnamed: C11.1, R12.2
unnamed: R3.2, R7.1, U2.31 (ADRSEL)
unnamed: C5.2, R11.2, U2.26 (AVIN)
unnamed: C12.1, U2.7 (BOOT)
unnamed: C1.2, R1.1, R2.1, R3.1, R4.1, U2.4 (BP1V5)
unnamed: C1.1, U2.5 (DRTN)
unnamed: C8.1, R8.1, R9.2, U2.27 (EN/UVLO)
unnamed: C13.2, R13.1, U2.34 (GOSNS)
unnamed: R1.2, R5.2, U2.32 (MSEL1)
unnamed: C10.1, U2.28 (VDD5)
unnamed: C13.1, R14.2, U2.33 (VOSNS)
unnamed: R4.2, R10.1, U2.30 (VSEL)

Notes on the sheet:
TPS546D24A is a Buck regulator that steps 4.5-5.5V down to 1.2V @ 20A for the BM1368
https://webench.ti.com/appinfo/webench/scripts/SDP.cgi?ID=3808DBEB40D18F5D
Input 4.5-5.5V
PGD is an open drain output from the TPS546D24. Pull up to 3.3V
I2C ADDR = 0x24
Output 1.2V nominal 20A max
Connect at U3 Pin 37

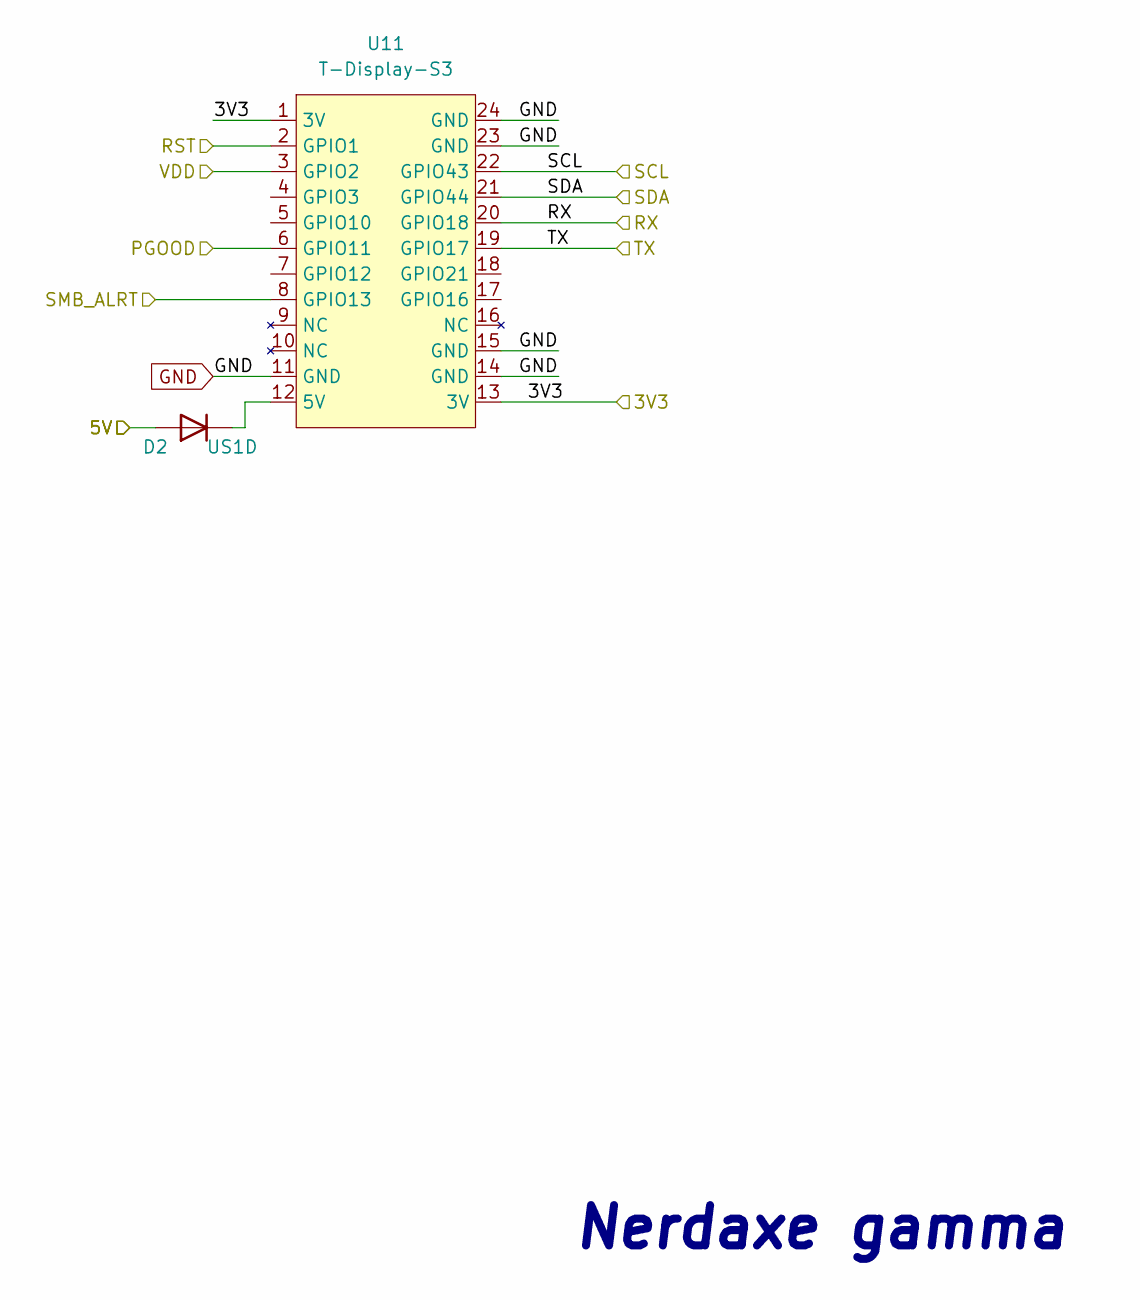
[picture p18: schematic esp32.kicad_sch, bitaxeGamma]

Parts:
D2: US1D; D_SMA
U11: T-Display-S3

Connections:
/3V3: U11.1 (3V), U11.13 (3V); also elsewhere on the board
/5V: D2.2 (A); also elsewhere on the board
/Power/PGOOD: U11.6 (GPIO11); also elsewhere on the board
/Power/PMB_ALRT: U11.8 (GPIO13); also elsewhere on the board
/RST: U11.2 (GPIO1); also elsewhere on the board
/RX: U11.20 (GPIO18); also elsewhere on the board
/SCL: U11.22 (GPIO43); also elsewhere on the board
/SDA: U11.21 (GPIO44); also elsewhere on the board
/TX: U11.19 (GPIO17); also elsewhere on the board
/VDD: U11.3 (GPIO2); also elsewhere on the board
unnamed: D2.1 (K), U11.12 (5V)

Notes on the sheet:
Nerdaxe gamma

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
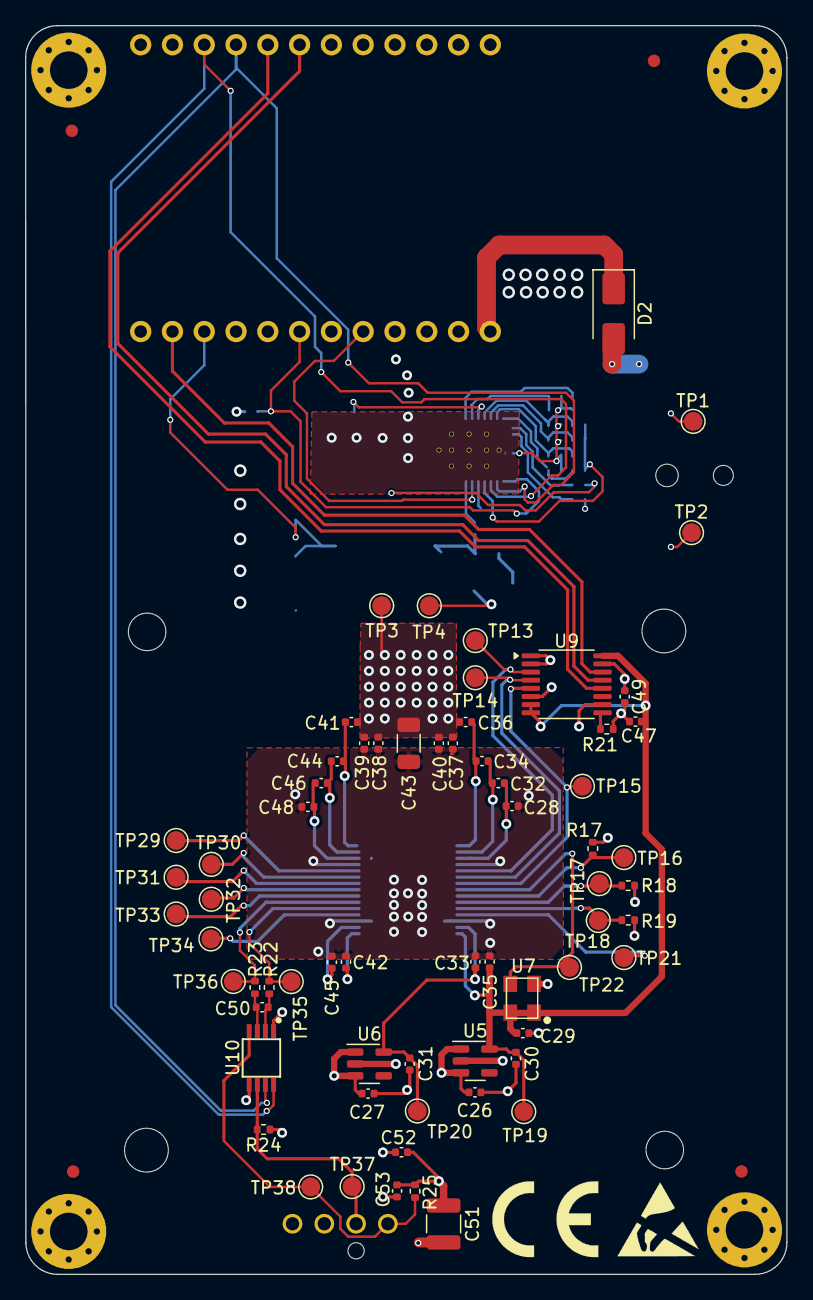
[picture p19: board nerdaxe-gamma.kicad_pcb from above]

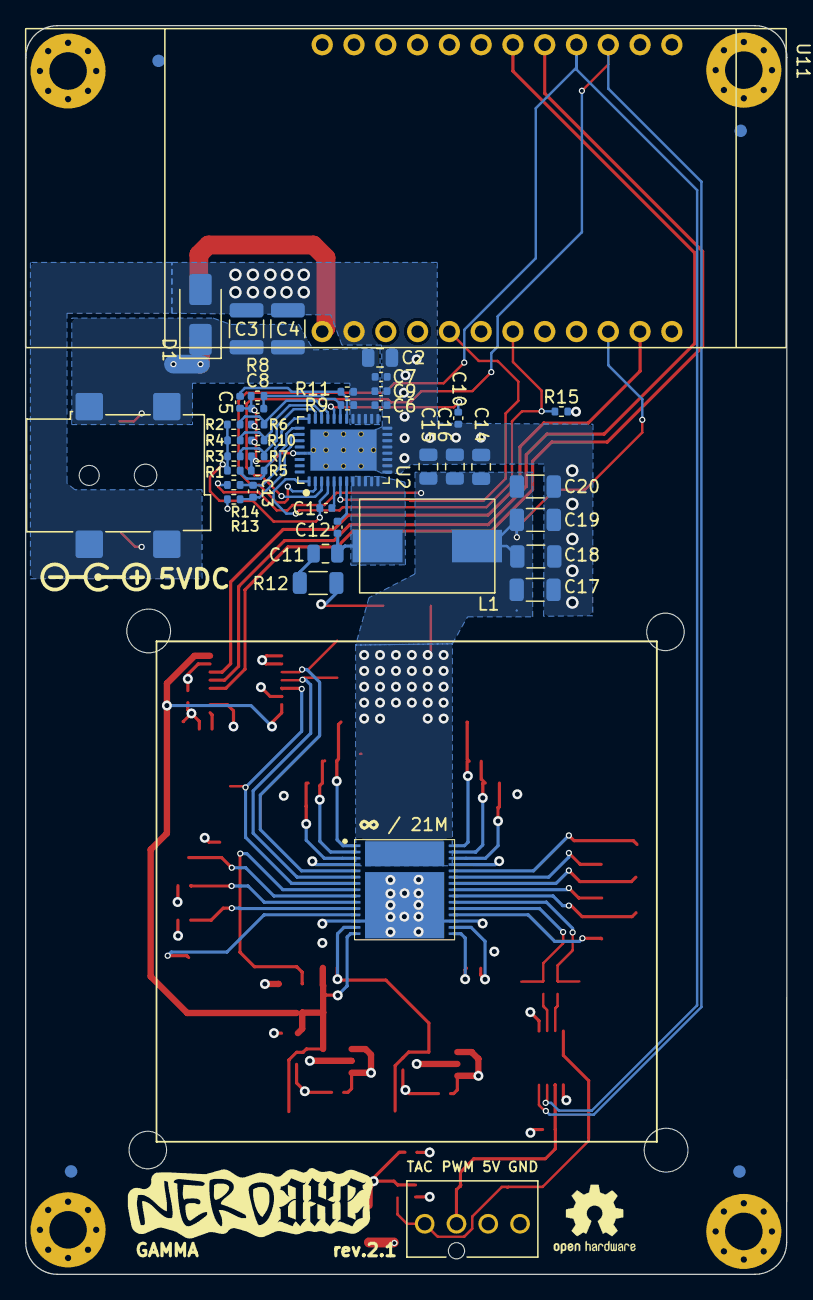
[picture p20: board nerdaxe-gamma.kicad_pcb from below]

Board: 4 copper layers, 60.8 x 99.8 mm, 126 parts (48 on the bottom side), 58 nets.

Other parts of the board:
R17: 10k; R_0402_1005Metric
R18, R19: 1k; R_0402_1005Metric
R24: 5.6k; R_0402_1005Metric

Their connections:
/3V3: R24.2; also elsewhere on the board
/Fan/FAN_TACH: R24.1; also elsewhere on the board
